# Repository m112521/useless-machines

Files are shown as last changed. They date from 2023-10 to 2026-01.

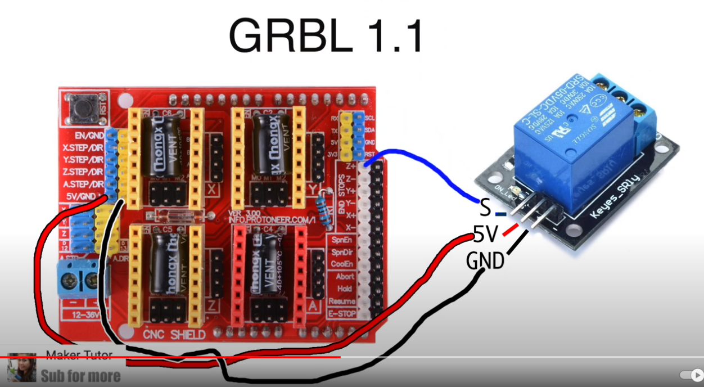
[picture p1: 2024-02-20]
imgs/relay-setup.PNG

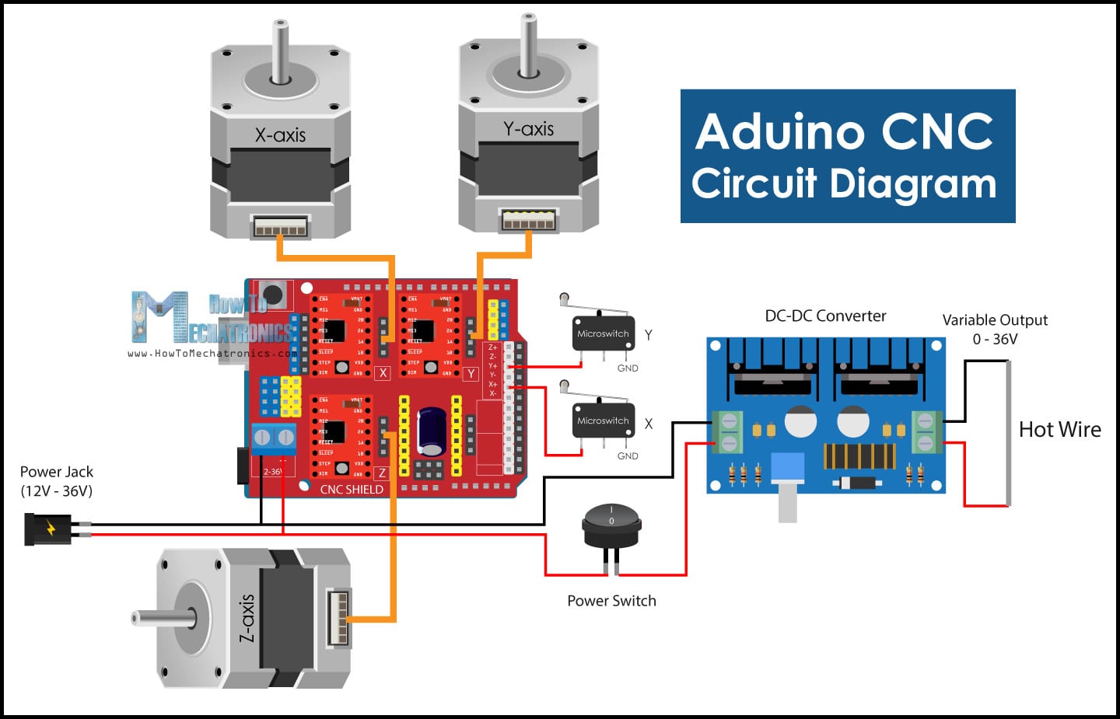
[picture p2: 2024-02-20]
imgs/hotwire-setup.jpg

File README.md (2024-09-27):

# Useless Machines WP

> A useless machine is a device which has a function but no direct purpose (a guy from MIT)

Heavily inspired by Nadya Peek's Modular Machines and those guys from GitHub (I took the pulley and the rack from them)

TBD:
- [ ] wires enclosing
- [ ] insert m3 epoxy for table screwable
- [ ] Basement for the whole machine
- [ ] Calib Z via Camera
- [ ] PCBTraceGenerator.gh  ->  [RhinoCAM](https://mecsoft.com/PostProcessors/MILL/GRBL-MM.spm) G-code

- [ ] PCB ESP32 MotorShield milling test
- [ ] Gh non-planar milling (polystyrene) -> Gcode
- [ ] Gh Machine Generator with Young's modulus calculator
- [ ] Poopirka

- [ ] Wiring and test for H-bot (2xY)
- [ ] Printable KIT with brims + CV(arucoQR, bridge, RPiholder) + box(?)
- [ ] Knowledge graph: from abstraction to details

- [x] Gh collision simulation
- [x] RPi Pyserial to GRBL  
- [x] Modular linear axes (MLA)
- [x] MLA XY+ assembly
- [x] TCP to point2D using OpenCV
- [x] Gh SyncSim WS

- [x] fix tool holder
- [x] Add endstop hole
- [x] Make axis supports fastanable to axis and to the floor
- [x] Yong's modulus for 12, 18 plywood

Functionality check:
- [ ] CV weaving 
- [ ] Web/PDF WP
- [ ] Dremel Z -> PCBTraceGenerator.gh
- [ ] p5.js lib -> draw and gcode stream
https://docs.google.com/document/d/1zGq897flr5F2EenAS7bOPgM9schD1iEFRFdtpmhVqJQ/edit

Simulation

CNC Shield/GRBL config:

1. CNC Shield Jumpers
2. GRBL spindle speed

PySerial to GRBL:

```python
import serial
import time

# Open grbl serial port
s = serial.Serial('COM3', 115200)

# Wake up grbl
s.write(b"\r\n\r\n")
time.sleep(2)   # Wait for grbl to initialize 
s.flushInput()  # Flush startup text in serial input

s.write(str.encode('$X' + '\n'))
s.write(str.encode('$H' + '\n'))
s.write(str.encode('G21' + '\n'))
s.write(str.encode('G90' + '\n'))
s.write(str.encode('M3S500' + '\n'))
s.write(str.encode('G0X5.000Y5.000' + '\n'))
s.write(str.encode('G1X42.7384Y52.0254F400' + '\n'))
s.write(str.encode('M3S0' + '\n'))
s.write(str.encode('G1X100.1235Y100.1235F400' + '\n'))

s.close()    

```

WS stream grbl status:

```python
import serial
import time
from fastapi import FastAPI, Response, WebSocket
from fastapi.middleware.cors import CORSMiddleware
import cv_grbl_aruco as cnc

origins = ["*"]
app = FastAPI()
app.add_middleware(CORSMiddleware, allow_origins=origins, allow_credentials=True, allow_methods=["*"], allow_headers=["*"],)

cnc.home_machine()
cnc.draw_x(120, 90, 5)

m_pos = 0
#@app.on_event('startup')
#def init_data():
#    pass

@app.websocket("/ws")
async def websocket_endpoint(websocket: WebSocket):
    global m_pose
    global cnc
    await websocket.accept()
    try:
        while True:
            data = await websocket.receive_text()
            m_pos = cnc.get_machine_position()
            await websocket.send_text(f"{m_pos}")
            #if m_pose is not None:
            #    await websocket.send_text(f"Machine position: {m_pose}")
            #else:
            #    await websocket.send_text(f"Machine position: none")
    except Exception as e:
        print(e)
##ser.reset_input_buffer()

#cnc.home_machine()
#origin_px, top_right_pt, point_px = cnc.get_markers()
#if origin_px is not None:
    #px_per_mm = cnc.calc_px_per_mm(origin_px, top_right_pt, cnc.MARKER_SIZE_MM)
    #draw_x(120, 90, 5)
    #cnc.move_machine(point_px, origin_px, px_per_mm)
#else:
    #print("No markers found")

#input("  Press <Enter> to exit and disable grbl.")

# close serial
#cnc.s.close()

```

-------------------------------------

Instructions:

Carrige 1:

https://github.com/m112521/useless-machines/assets/85460283/1d898f0c-5cae-43d9-b15b-1ca97f9952e6

Carrige 2:

https://github.com/m112521/useless-machines/assets/85460283/568b16e4-cb6c-4cd2-8910-7a5e2f30e3df

Carrige 3:

https://github.com/m112521/useless-machines/assets/85460283/dc9f5c50-31b6-4a93-bcf2-43fd21f10367

Carrige 4:

https://github.com/m112521/useless-machines/assets/85460283/1df0a3c2-96c0-4288-9bb8-245eb9bfb2f2

Rail: 

https://github.com/m112521/useless-machines/assets/85460283/70a19164-39d7-4d2d-80c0-af41929da47c

Axis X-1:

https://github.com/m112521/useless-machines/assets/85460283/7156194f-57ff-49da-a9d0-40450719a380

Axis X-2:

https://github.com/m112521/useless-machines/assets/85460283/d27853ad-4865-437f-8faa-c0686a177267

Axis X-endstop:

https://github.com/m112521/useless-machines/assets/85460283/16b9a3ca-a30e-440b-8486-f2dd495ec5e4

Axis XV-support:

https://github.com/m112521/useless-machines/assets/85460283/c26f3623-e518-4918-be77-d1f35b5745ff

Wheel-X:

https://github.com/m112521/useless-machines/assets/85460283/9568cd56-e5c2-4810-b618-4dbb1be0e70f

Carrige VY-holderVX

https://github.com/m112521/useless-machines/assets/85460283/4576e473-dfea-46f0-a778-e4fb95ce2ffa

Assembly VY-VX:

https://github.com/m112521/useless-machines/assets/85460283/b02ba156-daf3-4695-9696-71cce22d752f

Assembly-VX-FOR-HY:

https://github.com/m112521/useless-machines/assets/85460283/e208e78f-c716-4a84-b4d4-77ff1d42ef49

Assembly-VXHY:

https://github.com/m112521/useless-machines/assets/85460283/3cd34c90-32d5-4921-98f5-b61b05a48a90

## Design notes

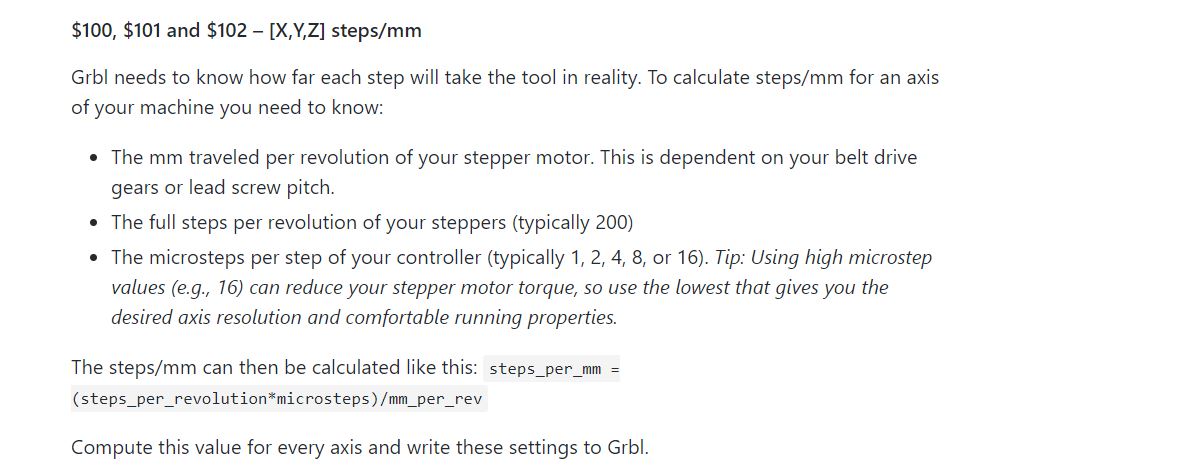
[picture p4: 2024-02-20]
imgs/Setting1.jpg

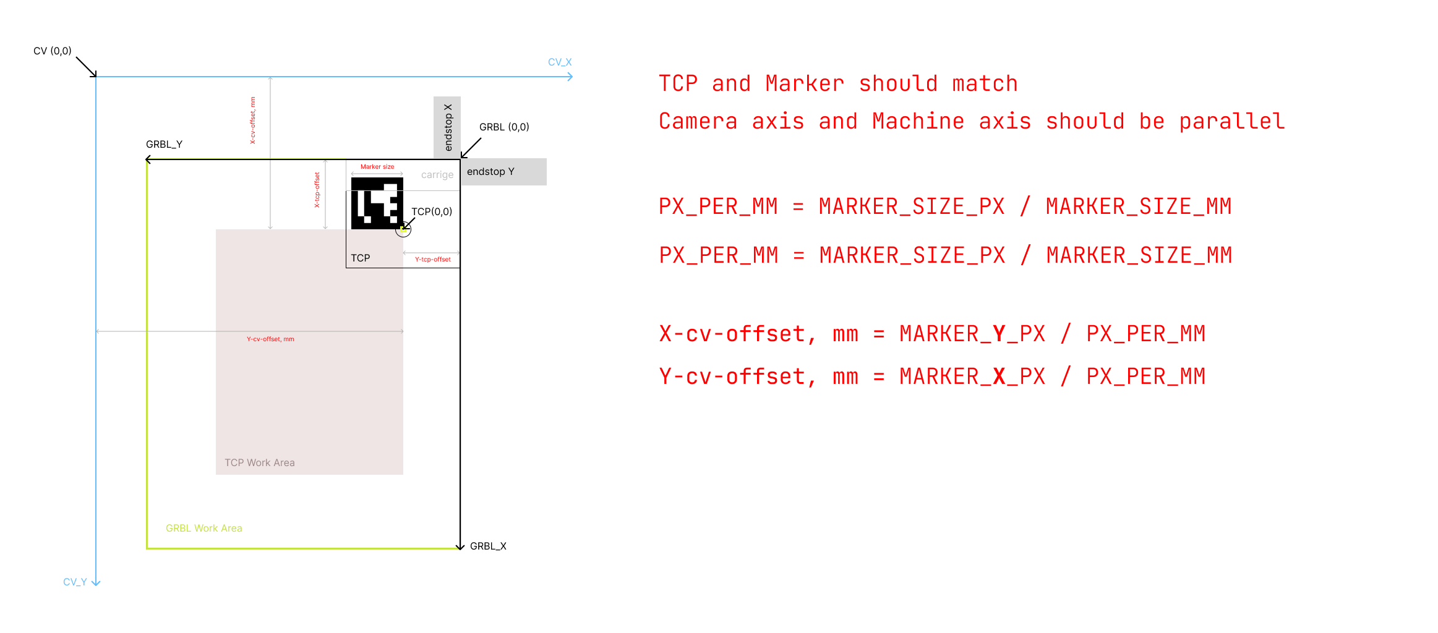
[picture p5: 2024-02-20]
imgs/Basis.png

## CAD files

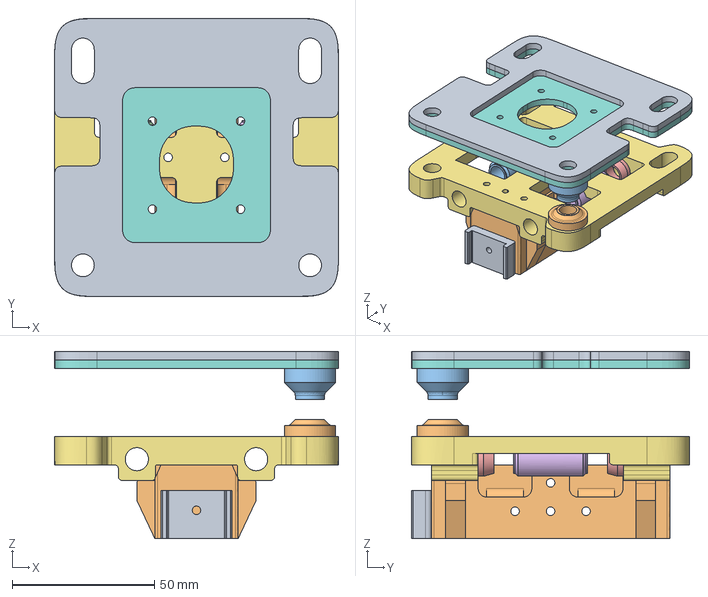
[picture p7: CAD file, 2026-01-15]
STEP/carrige_assembly_t12_w50.stp
100.0 x 97.9 x 66.0 mm

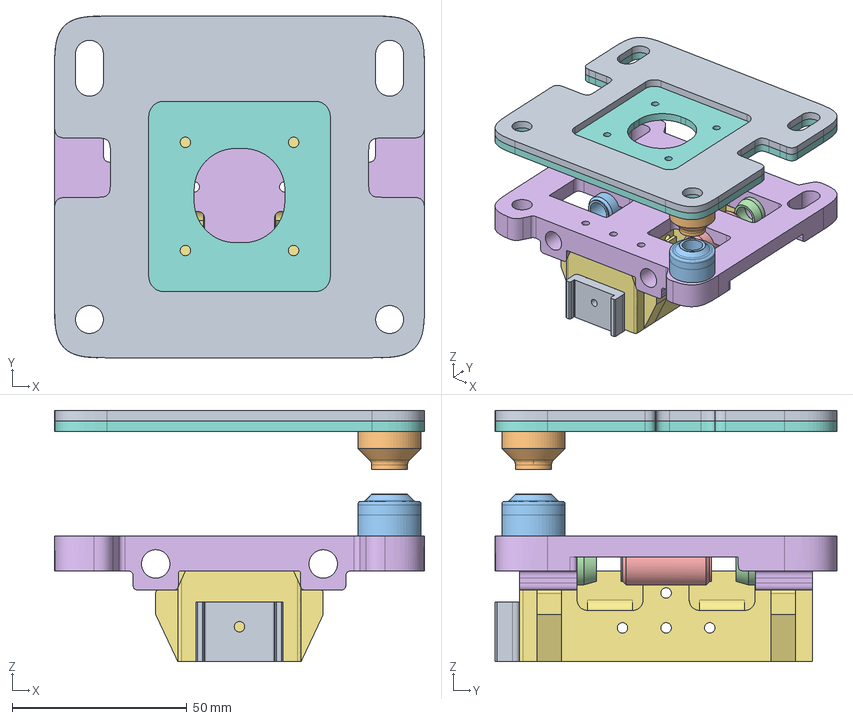
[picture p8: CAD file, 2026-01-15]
STEP/carrige_assembly_t18_w50.stp
106.0 x 97.9 x 72.0 mm

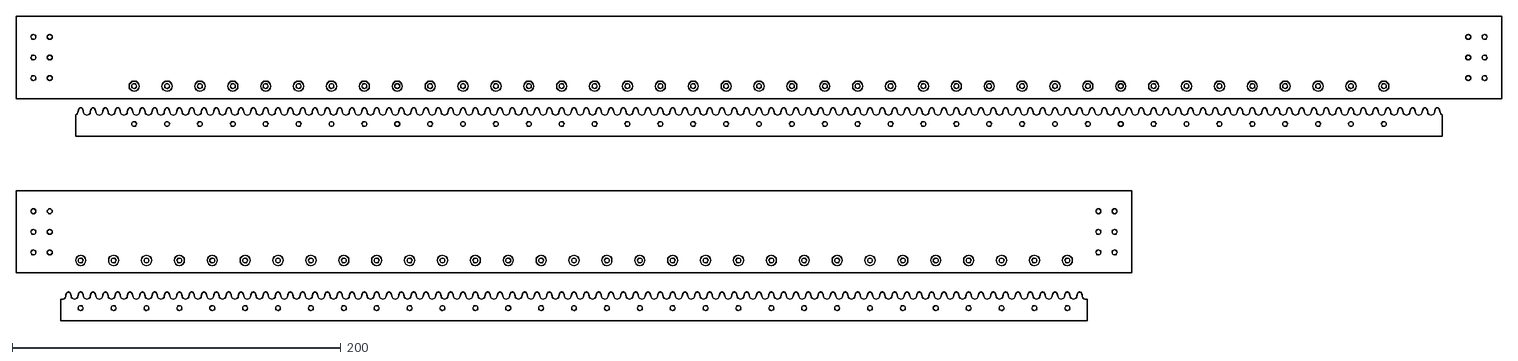
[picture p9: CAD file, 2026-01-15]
CAD/axis_A1.dxf
903.3 x 185.0

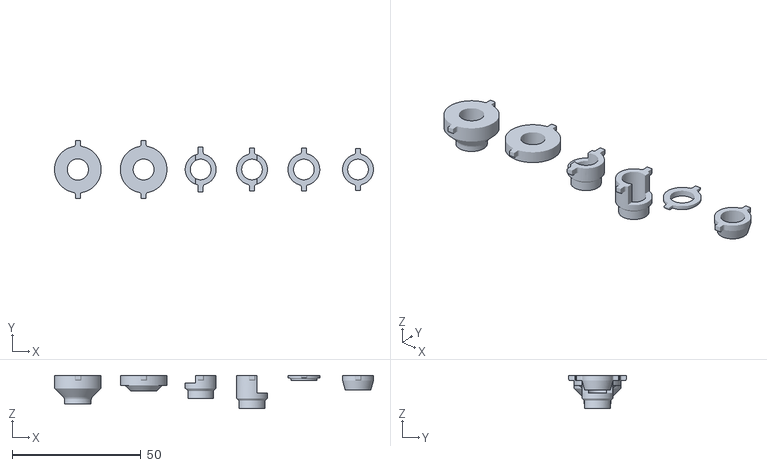
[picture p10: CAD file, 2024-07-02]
KIT/sapcers.stl
123.7 x 22.5 x 12.9

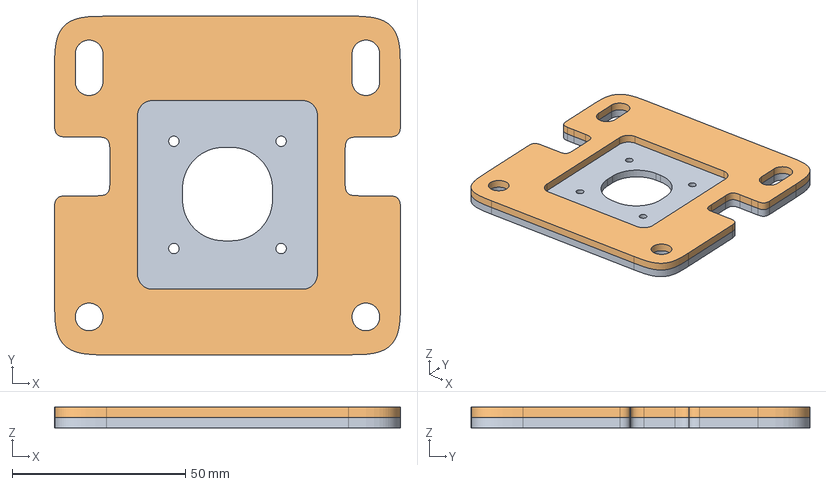
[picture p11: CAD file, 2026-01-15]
STEP/carrige_bread_t12_w50.stp
100.0 x 97.9 x 6.00 mm

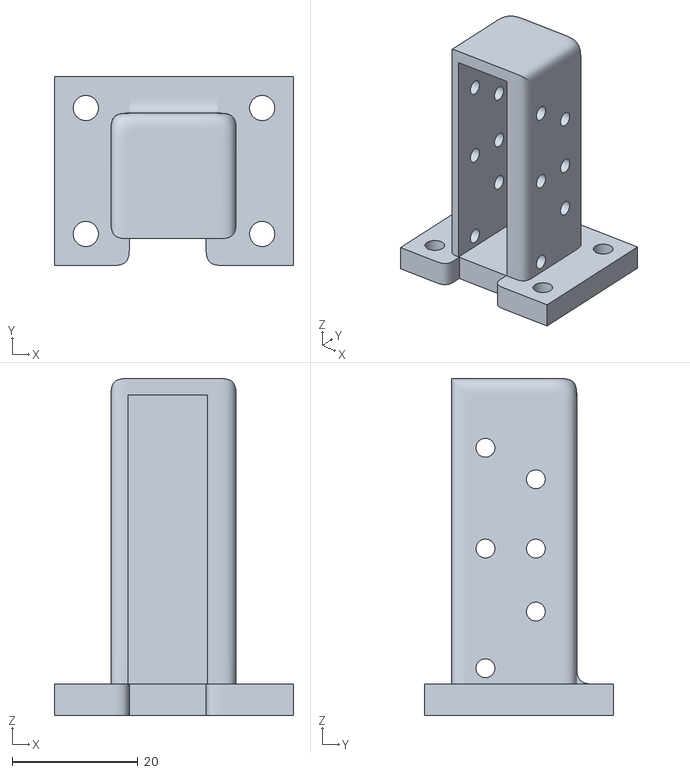
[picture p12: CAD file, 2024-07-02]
STL/wheeledLeg-VX.stl
38.0 x 30.0 x 53.5

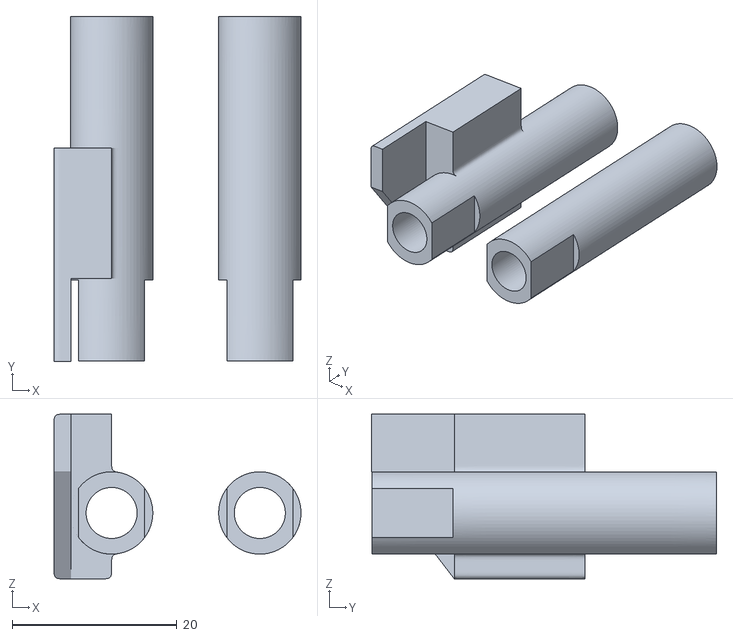
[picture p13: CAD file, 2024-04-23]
STL/Z-axis/Spacer.stl
30.0 x 41.9 x 20.0

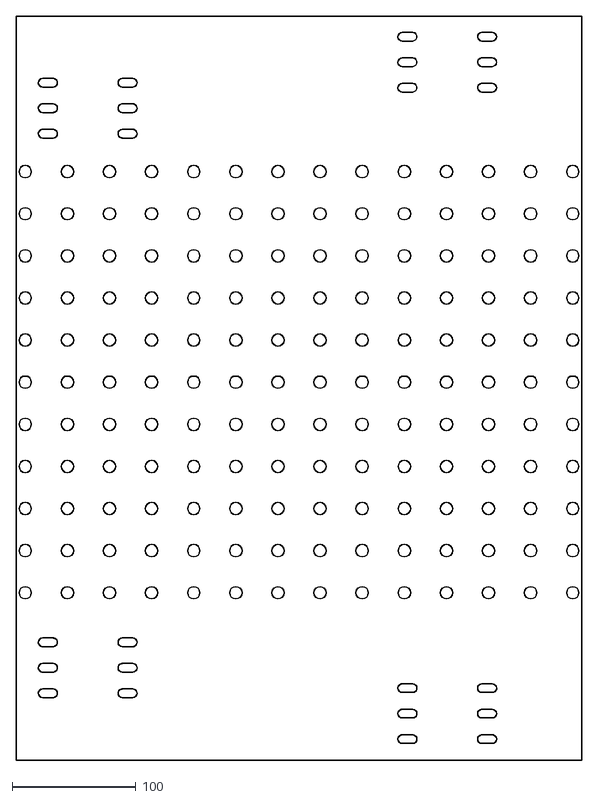
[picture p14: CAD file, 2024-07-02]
CAD/baseD10.dxf
456.8 x 600.6

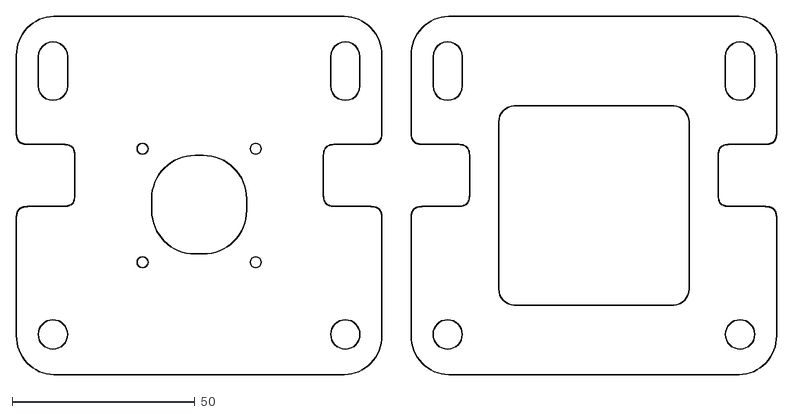
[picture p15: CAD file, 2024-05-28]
KIT/carrige_motorized.dxf
208.0 x 98.0

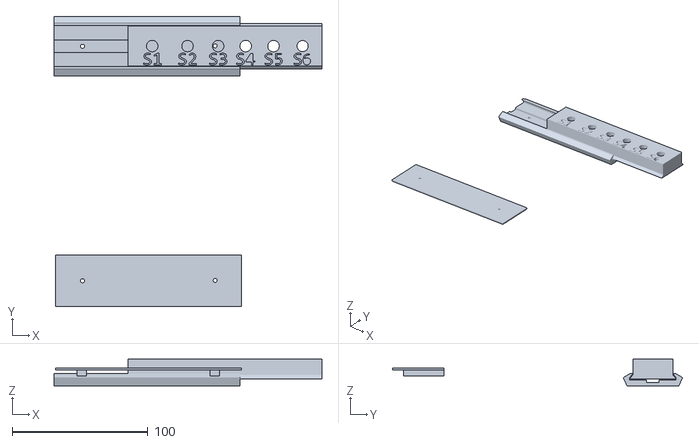
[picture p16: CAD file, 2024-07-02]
STL/drillRig.stl
197.4 x 213.8 x 19.9

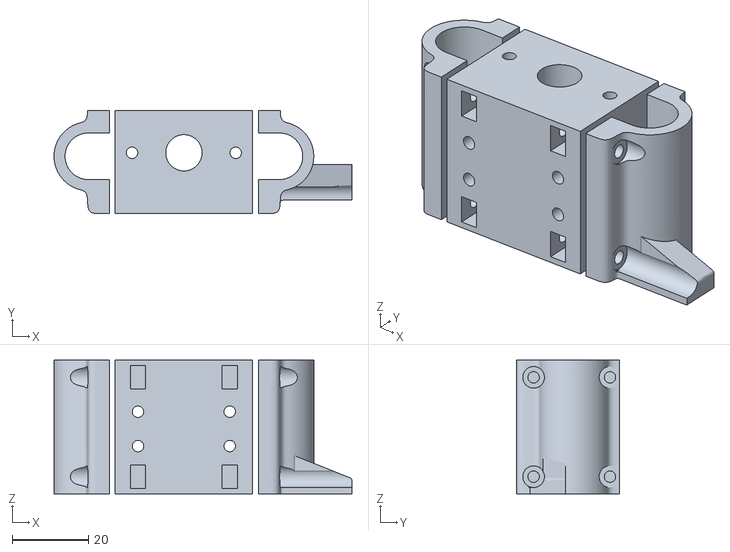
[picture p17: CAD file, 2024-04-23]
STL/Z-axis/BearingHolder_v02.stl
78.0 x 27.0 x 35.0

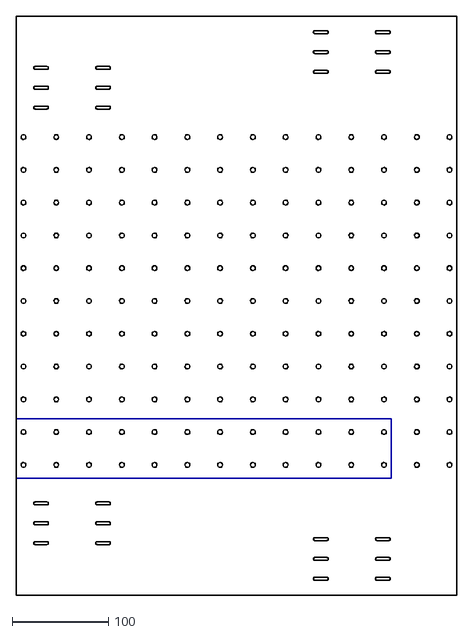
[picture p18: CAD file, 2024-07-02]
CAD/baseD5.dxf
456.8 x 600.6

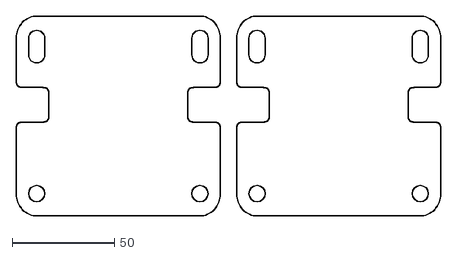
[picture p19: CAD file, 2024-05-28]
KIT/carrige_idle.dxf
208.0 x 98.0

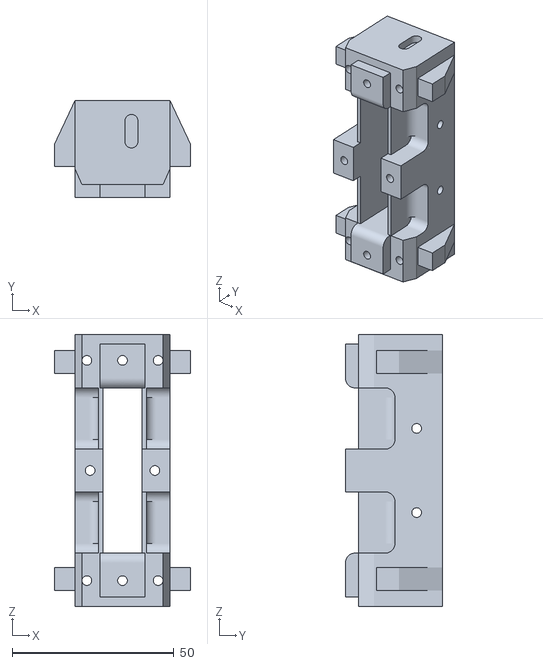
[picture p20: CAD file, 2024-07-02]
STL/VX-hoder.stl
42.0 x 30.0 x 84.0

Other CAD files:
STL/Z-axis/ToolHolder_v01.stl
CAD/baseD3.dxf
KIT/racks.dxf
STEP/carrige_bread_t18_w50.stp
CAD/baseD6.dxf
CAD/cameraBeam.dxf
CAD/flexicamRail.dxf
STEP/carrige_cheese_t12_w50.stp
STEP/carrige_cheese_t18_w50.stp
STEP/carrige_endstopHolder.stp
STEP/carrige_jam_t12_w50.stp
STEP/carrige_jam_t18_w50.stp
STL/BottomCarrigePLA.stl
STL/BottomCarrigePLA2.stl
STL/BottomCarrigePLA3.stl
STL/Z-axis/BearingHolder.stl
STL/Z-axis/Plate.stl
STL/Z-axis/RailHolderBottom.stl
STL/Z-axis/RailHolderTop.stl
STL/Z-axis/RailHolderTop_spacered.stl
STL/Z-axis/StepperHolders.stl
STL/axisSupport.stl
STL/axisSupportStatic.stl
STL/axisSupport_v2.stl
STL/bearingSpacer.stl
STL/bottomBearingSpacers.stl
STL/bottomBearingSpacers_v2.stl
STL/carrigeBracket.stl
STL/endstopHolder.stl
STL/endstopHolderVX.stl
STL/endstopHolder_v2.stl
STL/foot.stl
STL/nemaHolder.stl
STL/perpAxisHolderArched.stl
STL/pinion.stl

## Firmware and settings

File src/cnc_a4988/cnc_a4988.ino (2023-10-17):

#include <AccelStepper.h>
#define limitX 9 //Limit pins: X->9 , Y->10 , Z->11

AccelStepper Xaxis(1, 2, 5); // pin 2 = step, pin 5 = direction // Y: step=3, dir=6; // Z: step=4 dir=7
AccelStepper Yaxis(1, 3, 6);

const byte enablePin = 8;
const int speed = -1000;

void setup()
{
  pinMode(enablePin, OUTPUT);
  pinMode(limitX, INPUT);

  digitalWrite(enablePin, LOW);

  Xaxis.setMaxSpeed(12800);
  Xaxis.setSpeed(speed); // 1000

  Yaxis.setMaxSpeed(12800);
  Yaxis.setSpeed(1000);

  Serial.begin(9600);
}

void loop()
{
  Xaxis.runSpeed();
  int endX = digitalRead(limitX);

  if (endX) {
    Xaxis.setSpeed(-speed);
  }

  // delay(2000);
  // Xaxis.stop();
  // Yaxis.runSpeed();
}

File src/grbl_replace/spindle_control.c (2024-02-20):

/*
  spindle_control.c - spindle control methods
  Part of Grbl
 
  PEN_SERVO update by Bart Dring 8/2017
  Copyright (c) 2012-2017 Sungeun K. Jeon for Gnea Research LLC
  Copyright (c) 2009-2011 Simen Svale Skogsrud
 
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
  You should have received a copy of the GNU General Public License
  along with Grbl.  If not, see <http://www.gnu.org/licenses/>.
*/
 
#include "grbl.h"
 
/*
Pen Servo: 
 
For a pen bot I want to use the spindle PWM to control a servo
When the spindle is on, the servo moves the pen down
When it is off the pen moves up
 
The spindle output is using a PWM, but we need to adjust that 
 
We only need a rough 
 
Use 1024 prescaler to get. ... 16,000,000 Mhz  / 1024 = 15625 Hz
It is an 8 bit timer so 15625 / 256 = 61 Hz. This is pretty close the the 50Hz recommended for servos
Each tick = 0.000064sec 
One end of servo is 0.001 sec (0.001 / 0.000064 = 15.6 ticks)
The other end is 0.002 sec (0.002 / 0.000064 = 31 ticks)
 
 
*/
 
#define PEN_SERVO
// these are full travel values. If you want to move less than full travel adjust these values
// If your servo is going the wrong way, swap them.
#define PEN_SERVO_DOWN     16      
#define PEN_SERVO_UP       31        
 
#ifdef VARIABLE_SPINDLE
  static float pwm_gradient; // Precalulated value to speed up rpm to PWM conversions.
#endif
 
 
void spindle_init()
{
  #ifdef VARIABLE_SPINDLE
 
    SPINDLE_PWM_DDR |= (1<<SPINDLE_PWM_BIT); // Configure as PWM output pin.
     
    #ifndef PEN_SERVO 
   
        // Configure variable spindle PWM and enable pin, if required. On the Uno, PWM and enable are
        // combined unless configured otherwise.
         
        SPINDLE_TCCRA_REGISTER = SPINDLE_TCCRA_INIT_MASK; // Configure PWM output compare timer
        SPINDLE_TCCRB_REGISTER = SPINDLE_TCCRB_INIT_MASK;
     
    #else
        #ifdef CPU_MAP_ATMEGA2560
         
        // not supported yet
         
      #else
         
        SPINDLE_TCCRA_REGISTER = (1<<COM2A1) | ((1<<WGM20) | (1<<WGM21));
        TCCR2B = (1<<CS22) | (1 <<CS21) | (1<<CS20);
         
      #endif
    #endif
     
     
     
    #ifdef USE_SPINDLE_DIR_AS_ENABLE_PIN
      SPINDLE_ENABLE_DDR |= (1<<SPINDLE_ENABLE_BIT); // Configure as output pin.
    #else
      SPINDLE_DIRECTION_DDR |= (1<<SPINDLE_DIRECTION_BIT); // Configure as output pin.
    #endif
 
    pwm_gradient = SPINDLE_PWM_RANGE/(settings.rpm_max-settings.rpm_min);
 
  #else
 
    // Configure no variable spindle and only enable pin.
    SPINDLE_ENABLE_DDR |= (1<<SPINDLE_ENABLE_BIT); // Configure as output pin.
    SPINDLE_DIRECTION_DDR |= (1<<SPINDLE_DIRECTION_BIT); // Configure as output pin.
 
  #endif
 
  spindle_stop();
}
 
 
uint8_t spindle_get_state()
{
    #ifdef VARIABLE_SPINDLE
    #ifdef USE_SPINDLE_DIR_AS_ENABLE_PIN
          // No spindle direction output pin. 
            #ifdef INVERT_SPINDLE_ENABLE_PIN
              if (bit_isfalse(SPINDLE_ENABLE_PORT,(1<<SPINDLE_ENABLE_BIT))) { return(SPINDLE_STATE_CW); }
        #else
                if (bit_istrue(SPINDLE_ENABLE_PORT,(1<<SPINDLE_ENABLE_BIT))) { return(SPINDLE_STATE_CW); }
        #endif
    #else
      if (SPINDLE_TCCRA_REGISTER & (1<<SPINDLE_COMB_BIT)) { // Check if PWM is enabled.
        if (SPINDLE_DIRECTION_PORT & (1<<SPINDLE_DIRECTION_BIT)) { return(SPINDLE_STATE_CCW); }
        else { return(SPINDLE_STATE_CW); }
      }
    #endif
    #else
        #ifdef INVERT_SPINDLE_ENABLE_PIN
          if (bit_isfalse(SPINDLE_ENABLE_PORT,(1<<SPINDLE_ENABLE_BIT))) {
        #else
          if (bit_istrue(SPINDLE_ENABLE_PORT,(1<<SPINDLE_ENABLE_BIT))) {
        #endif
      if (SPINDLE_DIRECTION_PORT & (1<<SPINDLE_DIRECTION_BIT)) { return(SPINDLE_STATE_CCW); }
      else { return(SPINDLE_STATE_CW); }
    }
    #endif
    return(SPINDLE_STATE_DISABLE);
}
 
 
// Disables the spindle and sets PWM output to zero when PWM variable spindle speed is enabled.
// Called by various main program and ISR routines. Keep routine small, fast, and efficient.
// Called by spindle_init(), spindle_set_speed(), spindle_set_state(), and mc_reset().
void spindle_stop()
{
     
  #ifndef PEN_SERVO 
     
      #ifdef VARIABLE_SPINDLE
        SPINDLE_TCCRA_REGISTER &= ~(1<<SPINDLE_COMB_BIT); // Disable PWM. Output voltage is zero.
        #ifdef USE_SPINDLE_DIR_AS_ENABLE_PIN
          #ifdef INVERT_SPINDLE_ENABLE_PIN
            SPINDLE_ENABLE_PORT |= (1<<SPINDLE_ENABLE_BIT);  // Set pin to high
          #else
            SPINDLE_ENABLE_PORT &= ~(1<<SPINDLE_ENABLE_BIT); // Set pin to low
          #endif
        #endif
      #else
        #ifdef INVERT_SPINDLE_ENABLE_PIN
          SPINDLE_ENABLE_PORT |= (1<<SPINDLE_ENABLE_BIT);  // Set pin to high
        #else
          SPINDLE_ENABLE_PORT &= ~(1<<SPINDLE_ENABLE_BIT); // Set pin to low
        #endif
      #endif
   
  #else   
    SPINDLE_OCR_REGISTER = PEN_SERVO_UP;    
  #endif
   
}
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

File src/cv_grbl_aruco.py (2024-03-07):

# 2. Undistort
import cv2
import numpy as np
from cv2 import aruco
import serial
import time
from scipy.spatial import distance


MARKER_SIZE_MM = 30
#PX_PER_MM = 1.3
s = serial.Serial('/dev/ttyACM0', 115200)


def load_camera_mtx():
    cameraMatrix = np.load('mu_code/params/cameraMatrix.npy')
    dist = np.load('mu_code/params/dist.npy')

    return cameraMatrix, dist


def undistort_img(img, cameraMatrix, dist):
    h,  w = img.shape[:2]
    newCameraMatrix, roi = cv2.getOptimalNewCameraMatrix(cameraMatrix, dist, (w,h), 1, (w,h))

    # No remapping
    undist_img = cv2.undistort(img, cameraMatrix, dist, None, newCameraMatrix)

    # Undistort with Remapping
    #mapx, mapy = cv2.initUndistortRectifyMap(cameraMatrix, dist, None, newCameraMatrix, (w,h), 5)
    #undist_img_re = cv2.remap(img, mapx, mapy, cv.INTER_LINEAR)

    # crop the image
    x, y, w, h = roi
    #undist_img = undist_img[y:y+h, x:x+w]

    return undist_img


def calc_px_per_mm(pt_bl, pt_tl, marker_size_mm):
    return distance.euclidean(pt_bl, pt_tl) / marker_size_mm


def translate_convert(pt, origin, px_per_mm):
    return (abs(pt[0]-origin[0])/px_per_mm, abs(pt[1]-origin[1])/px_per_mm)


def translate_convert_mm(pt, origin, px_per_mm):
    # swap X and Y because CNC_XY is fliped relative to OpenCV_XY
    return (abs(pt[1]-origin[1])/px_per_mm-5, abs(pt[0]-origin[0])/px_per_mm+5)


def get_machine_position():
    s.write(str.encode('?'))
    return s.readline().strip().decode('utf-8')


def home_machine():
    s.write(b"\r\n\r\n")
    time.sleep(2)   # Wait for grbl to initialize
    s.flushInput()  # Flush startup text in serial input
    # home and park aside
    #s.write(str.encode('M3S500' + '\n'))
    s.write(str.encode('$X' + '\n'))
    s.write(str.encode('$H' + '\n'))
    s.write(str.encode('G21' + '\n'))
    s.write(str.encode('G90' + '\n')) # G90 - absolute mode; G91 - relative mode
    s.write(str.encode('M3S500' + '\n'))
    rbl_out = s.readline()
    s.write(str.encode('G0X0.000Y90.000' + '\n'))
    grbl_out = s.readline()

    s.write(str.encode('?'))
    print(s.readline().strip().decode('utf-8'))

    time.sleep(30)


def get_all_markers(origin_px, px_per_mm, cameraMatrix, dist, origin_px_u):
    cap = cv2.VideoCapture(0)
    points = []

    aruco_dict = aruco.Dictionary_get(aruco.DICT_6X6_250)
    parameters =  aruco.DetectorParameters_create()

    while True:
        ret, frame = cap.read()
        gray = cv2.cvtColor(frame, cv2.COLOR_BGR2GRAY)

        # raw image
        corners, ids, _ = aruco.detectMarkers(gray, aruco_dict, parameters=parameters)
        frame_markers = aruco.drawDetectedMarkers(frame.copy(), corners, ids)

        # undistorted image
        frame_u = undistort_img(frame, cameraMatrix, dist)
        gray_u = cv2.cvtColor(frame, cv2.COLOR_BGR2GRAY)
        corners_u, ids_u, _ = aruco.detectMarkers(gray_u, aruco_dict, parameters=parameters)
        frame_markers_u = aruco.drawDetectedMarkers(frame_u.copy(), corners_u, ids_u)

        if (ids is not None):
            for pt in corners:
                point_px = (pt[0][0][0], pt[0][0][1])
                point_mm = translate_convert_mm(point_px, origin_px, px_per_mm)
                points.append(point_mm)
                print(f"RAW:\n{point_px}, {point_mm}")
            for pt_u in corners_u:
                point_px_u = (pt_u[0][0][0], pt_u[0][0][1])
                point_mm_u = translate_convert_mm(point_px_u, origin_px_u, px_per_mm)
                #points.append(point_mm_u)
                print(f"UND:\n{point_px_u}, {point_mm_u}")
            break
        else:
            print(f"Markers not found")
    cap.release()

    cv2.imshow('Markers', frame_markers)
    #compare_img = np.concatenate((frame_markers, frame_markers_u), axis=1)
    #cv2.imshow('Raw vs undistorted', compare_img)
    cv2.waitKey(0)
    cv2.destroyAllWindows()

    return points


def get_marker():
    cap = cv2.VideoCapture(0)
    frame_markers = None
    origin_px = None
    origin_px_u = None
    top_right_pt = None

    cameraMatrix, dist = load_camera_mtx()

    # UNDIST IMG -> find markers

    while True:
        ret, frame = cap.read()
        #smallFrame = cv2.resize(frame, (200, 200))
        gray = cv2.cvtColor(frame, cv2.COLOR_BGR2GRAY)
        aruco_dict = aruco.Dictionary_get(aruco.DICT_6X6_250)
        parameters =  aruco.DetectorParameters_create()
        corners, ids, _ = aruco.detectMarkers(gray, aruco_dict, parameters=parameters)
        frame_markers = aruco.drawDetectedMarkers(frame.copy(), corners, ids)

        frame_u = undistort_img(frame, cameraMatrix, dist)
        gray_u = cv2.cvtColor(frame_u, cv2.COLOR_BGR2GRAY)
        corners_u, ids_u, _ = aruco.detectMarkers(gray_u, aruco_dict, parameters=parameters)
        frame_markers_u = aruco.drawDetectedMarkers(frame_u.copy(), corners_u, ids_u)

        if (ids is not None) and min(ids)[0] == 1:
            min_id = min(ids)[0]
            origin_idx = np.where(ids==min_id)[0][0]

            min_id_u = min(ids_u)[0]
            origin_idx_u = np.where(ids_u==min_id_u)[0][0]
            print(corners[origin_idx])

            origin_px = (corners[origin_idx][0][0][0], corners[origin_idx][0][0][1])
            origin_px_u = (corners_u[origin_idx_u][0][0][0], corners_u[origin_idx_u][0][0][1])
            top_right_pt = (corners[origin_idx][0][1][0], corners[origin_idx][0][1][1])

            break
        else:
            print(f"Init marker not found")
    cap.release()

    compare_img = np.concatenate((frame_markers, frame_markers_u), axis=1)
    cv2.imshow('Markers', frame_markers)
    #cv2.imshow("Raw vs Undistorted", compare_img)
    cv2.waitKey(0)
    cv2.destroyAllWindows()

    print(f"ORIGIN_PX: {origin_px}")
    return (origin_px, top_right_pt, cameraMatrix, dist, origin_px_u)


def get_markers_static():
    frame = cv2.imread("mu_code/0.jpg")
    gray = cv2.cvtColor(frame, cv2.COLOR_BGR2GRAY)
    aruco_dict = aruco.Dictionary_get(aruco.DICT_6X6_250)
    parameters =  aruco.DetectorParameters_create()
    corners, ids, _ = aruco.detectMarkers(gray, aruco_dict, parameters=parameters)
    frame_markers = aruco.drawDetectedMarkers(frame.copy(), corners, ids)

    origin_px = None
    point_px = None
    if ids is not None:
        min_id = min(ids)[0]
        origin_idx = np.where(ids==min_id)[0][0]
        point_idx = np.where(ids!=min_id)[0][0]

        origin_px = (corners[origin_idx][0][0][0], corners[origin_idx][0][0][1])
        point_px = (corners[point_idx][0][0][0], corners[point_idx][0][0][1])

        print(f"ORIGIN_PX: {origin_px}\nPOINT_PX: {point_px}")

    return (origin_px, point_px)
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

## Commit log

2023-10-10 add test rail
    [BottomCarrigePLA.stl, BottomCarrigePLA2.stl, BottomCarrigePLA3.stl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]
2023-10-17 add gh slicer
    [endstopHolder.stl, flexicamRail.dxf]
2023-11-07 add gcode
    [axisSupport.stl, axisSupportStatic.stl, bearingSpacer.stl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]
2023-12-14 add frame joint
    [Joint.stl]
2023-12-19 add ful cv to grbl w aruco
2024-02-20 add all
    [config.h]
2024-03-01 add gh generator
    [BearingHolder.stl, Plate.stl, RailHolderBottom.stl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]
2024-03-07 add src
    [BearingHolder.stl, StepperHolders.stl]
2024-04-10 add esp32 ws gh
2024-04-23 fix everything
    [BearingHolder_v02.stl, Joint.stl, Spacer.stl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]
2024-05-21 add foot
    [foot.stl]
2024-05-28 add kit
    [carrige_idle.dxf, carrige_motorized.dxf, racks.dxf]
2024-06-07 add camera beam
    [cameraBeam.dxf]
2024-06-11 add e make up
    [endstopHolder_v2.stl]
2024-06-20 add drilling rig
    [baseD3.dxf, baseD6.dxf, drillRig.stl]
2024-07-02 add V axis
    [VX-hoder.stl, baseD10.dxf, baseD5.dxf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]

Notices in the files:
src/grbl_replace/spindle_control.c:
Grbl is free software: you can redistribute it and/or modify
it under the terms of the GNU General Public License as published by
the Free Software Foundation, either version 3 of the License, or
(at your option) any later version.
